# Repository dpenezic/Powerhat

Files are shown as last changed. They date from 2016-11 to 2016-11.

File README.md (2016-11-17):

# Powerhat
An rpi hat to shut down the raspberry pi gracefully

This hat includes the eeprom and a real time clock. A normal 12v relay is "powered" by capacitors, and when the power is switched off, The rpi is told to shut down and the capacitors allow approx 45 seconds for it to shut down before the relay cuts the power

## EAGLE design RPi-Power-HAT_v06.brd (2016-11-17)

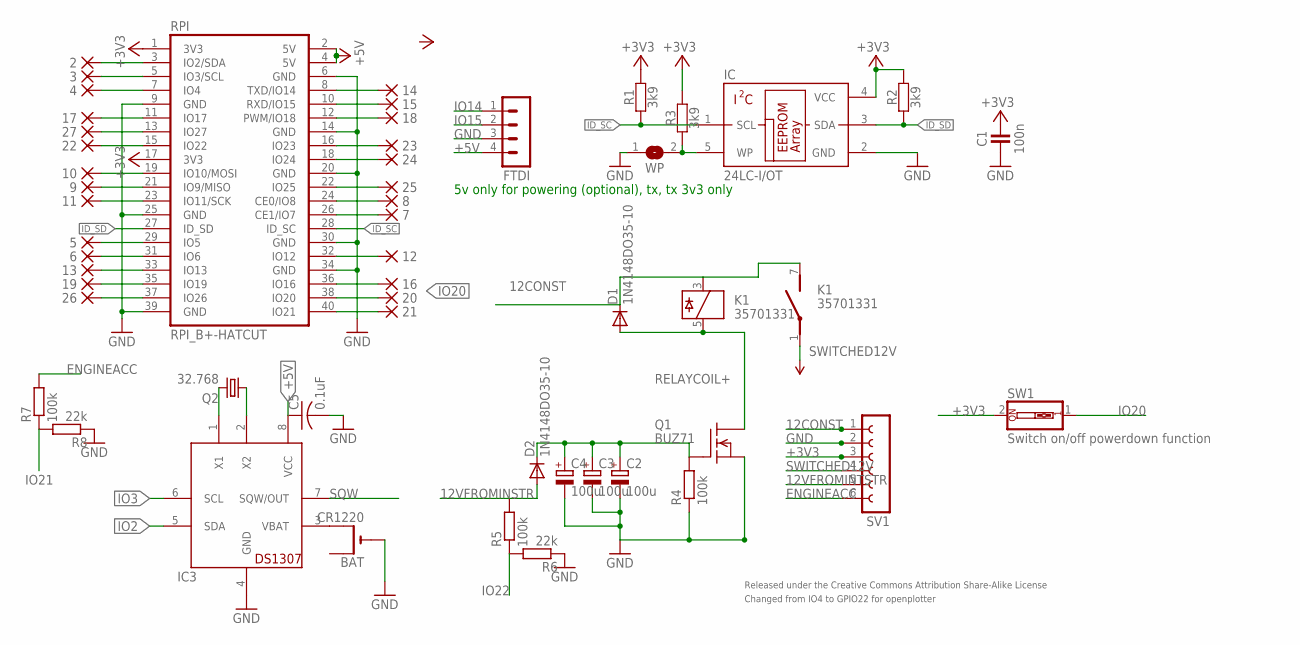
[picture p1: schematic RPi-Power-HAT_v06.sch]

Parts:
2, 3, 4, 5, 6, 7, 8, 9, 10, 11, 12, 13, 14, 15, 16, 17, 18, 19, 20, 21, 22, 23, 24, 25, 26, 27: PAD-1-1.6
BAT: CR1220; ADAFRUIT_CR1220-THM
C1: 100n; R0603
C2, C3, C4: 100u; E2-4
C5: 0.1uF; C025-025X050
D1, D2: 1N4148DO35-10; DO35-10
FTDI: MA04-1
IC: 24LC-I/OT; SOT23-5
IC3: DS1307; DIL08
K1: 35701331; REED
Q1: BUZ71; TO220
Q2: 32.768; TC38H
R1, R2, R3: 3k9; R0603
R4, R5, R7: 100k; 0207/2V
R6, R8: 22k; 0207/2V
RPI: RPI_B+-HATCUT; RPI-B+HAT_CUTOUT
SV1: FE06-1; FE06
SW1: Switch on/off powerdown function; EDG-01
WP: JUMPER2-NOCREAM; JUMPER2_NC

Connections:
12CONST: D1.C, K1.3, K1.7 (S), SV1.1
12VFROMINSTR: D2.A, R5.2
12VFROMINTSTR: SV1.5
+3V3: C1.2, IC.4 (VCC), R1.2, R2.2, R3.2, RPI.1 (3V3), RPI.17 (3V3), SV1.3, SW1.2
+5V: FTDI.4, IC3.8 (VCC), RPI.2 (5V), RPI.4 (5V)
ENGINEACC: R7.2, SV1.6
GND: BAT.-, C1.1, C2.-, C3.-, C4.-, C5.2, FTDI.3, IC.2 (GND), IC3.4 (GND), Q1.3 (S), R4.1, R6.1, R8.1, RPI.6 (GND), RPI.9 (GND), RPI.14 (GND), RPI.20 (GND), RPI.25 (GND), RPI.30 (GND), RPI.34 (GND), RPI.39 (GND), SV1.2, WP.1
ID_SC: IC.1 (SCL), R1.1, RPI.28 (ID_SC)
ID_SD: IC.3 (SDA), R2.1, RPI.27 (ID_SD)
IO2: 2.1, IC3.5 (SDA), RPI.3 (IO2/SDA)
IO3: 3.1, IC3.6 (SCL), RPI.5 (IO3/SCL)
IO4: 4.1, RPI.7 (IO4)
IO5: 5.1, RPI.29 (IO5)
IO6: 6.1, RPI.31 (IO6)
IO7: 7.1, RPI.26 (CE1/IO7)
IO8: 8.1, RPI.24 (CE0/IO8)
IO9: 9.1, RPI.21 (IO9/MISO)
IO10: 10.1, RPI.19 (IO10/MOSI)
IO11: 11.1, RPI.23 (IO11/SCK)
IO12: 12.1, RPI.32 (IO12)
IO13: 13.1, RPI.33 (IO13)
IO14: 14.1, FTDI.1, RPI.8 (TXD/IO14)
IO15: 15.1, FTDI.2, RPI.10 (RXD/IO15)
IO16: 16.1, RPI.36 (IO16)
IO17: 17.1, RPI.11 (IO17)
IO18: 18.1, RPI.12 (PWM/IO18)
IO19: 19.1, RPI.35 (IO19)
IO20: 20.1, RPI.38 (IO20), SW1.1
IO21: 21.1, R7.1, R8.2, RPI.40 (IO21)
IO22: 22.1, R5.1, R6.2, RPI.15 (IO22)
IO23: 23.1, RPI.16 (IO23)
IO24: 24.1, RPI.18 (IO24)
IO25: 25.1, RPI.22 (IO25)
IO26: 26.1, RPI.37 (IO26)
IO27: 27.1, RPI.13 (IO27)
unnamed: C2.+, C3.+, C4.+, D2.C, Q1.1 (G), R4.2
unnamed: IC3.1 (X1), Q2.2
unnamed: IC3.2 (X2), Q2.1
unnamed: BAT.+2 (+1), IC3.3 (VBAT)
RELAYCOIL+: D1.A, K1.5, Q1.2 (D)
SQW: IC3.7 (SQW/OUT)
SWITCHED12V: K1.1, SV1.4
WP: IC.5 (WP), R3.1, WP.2

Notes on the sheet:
Released under the Creative Commons Attribution Share-Alike License
5v only for powering (optional), tx, tx 3v3 only
Changed from IO4 to GPIO22 for openplotter

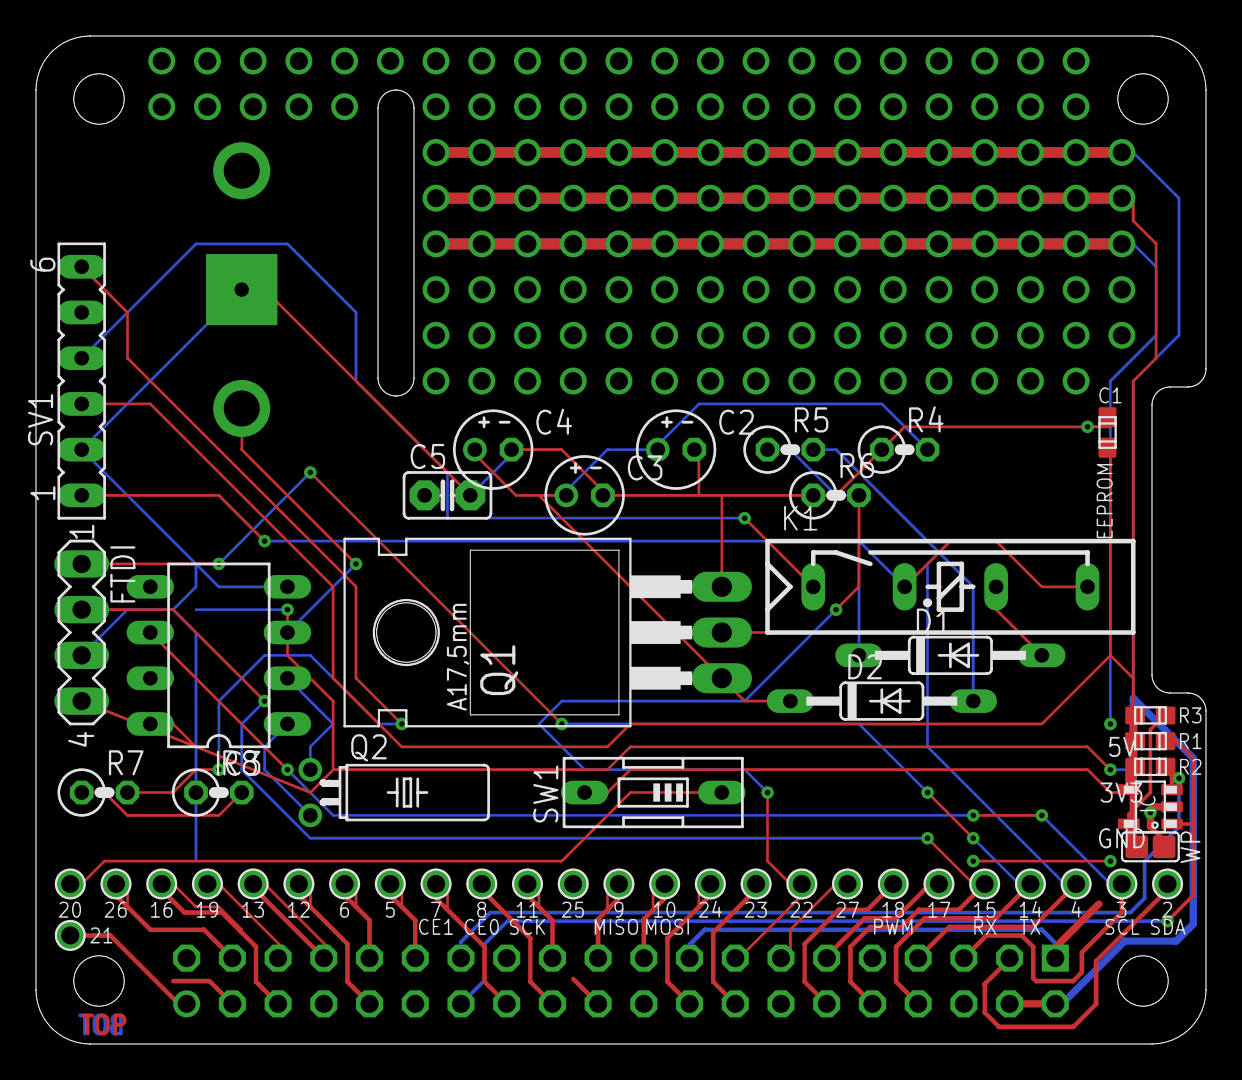
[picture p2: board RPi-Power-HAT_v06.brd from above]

Board: 2 copper layers, 65.0 x 56.0 mm, 52 parts (1 on the bottom side), 41 nets.
